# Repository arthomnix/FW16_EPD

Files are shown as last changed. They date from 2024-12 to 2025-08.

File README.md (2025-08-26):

# Framework Laptop 16 Touchscreen E-Paper Input Module

Touchscreen E-paper medium size input module for the Framework Laptop 16

_As featured on the [Framework 16 product page](https://frame.work/laptop16) and [Framework 2nd Gen Event](https://www.youtube.com/watch?v=-8k7jTF_JCg)_

Picture of prototype touchscreen e-paper input module installed in the right hand side of a Framework Laptop 16, showing the Framework logo and handwritten text saying 'Hi!'

**Firmware and software:** https://github.com/arthomnix/epd_firmware (also mirrored on [Tangled](https://tangled.sh/@arthomnix.dev/eepy))

## Legal

Copyright © 2024 arthomnix

This work is licensed under [Creative Commons Attribution-ShareAlike 4.0 International](https://creativecommons.org/licenses/by-sa/4.0).

Framework Laptop 16 Input Module footprints (`InputModule.pretty` folder) © 2023 Framework Computer, Inc. Licensed under [Creative Commons Attribution 4.0 International](https://creativecommons.org/licenses/by/4.0). Original available at https://github.com/FrameworkComputer/InputModules.

Hirose FH34SRJ footprints and symbols (`Hirose_FPC.pretty` folder; `FH34SRJ_*.kicad_sym`) © 2013-2024 SnapMagic. Licensed under [Creative Commons Attribution-ShareAlike 4.0 International](https://creativecommons.org/licenses/by-sa/4.0) with [Design Exception 1.0](https://www.snapeda.com/about/FAQ/#designexception). Originals available at https://www.snapeda.com/parts/FH34SRJ-6S-0.5SH%2850%29/Hirose%20Electric/view-part and https://www.snapeda.com/parts/FH34SRJ-24S-0.5SH%2850%29/Hirose%20Electric/view-part.

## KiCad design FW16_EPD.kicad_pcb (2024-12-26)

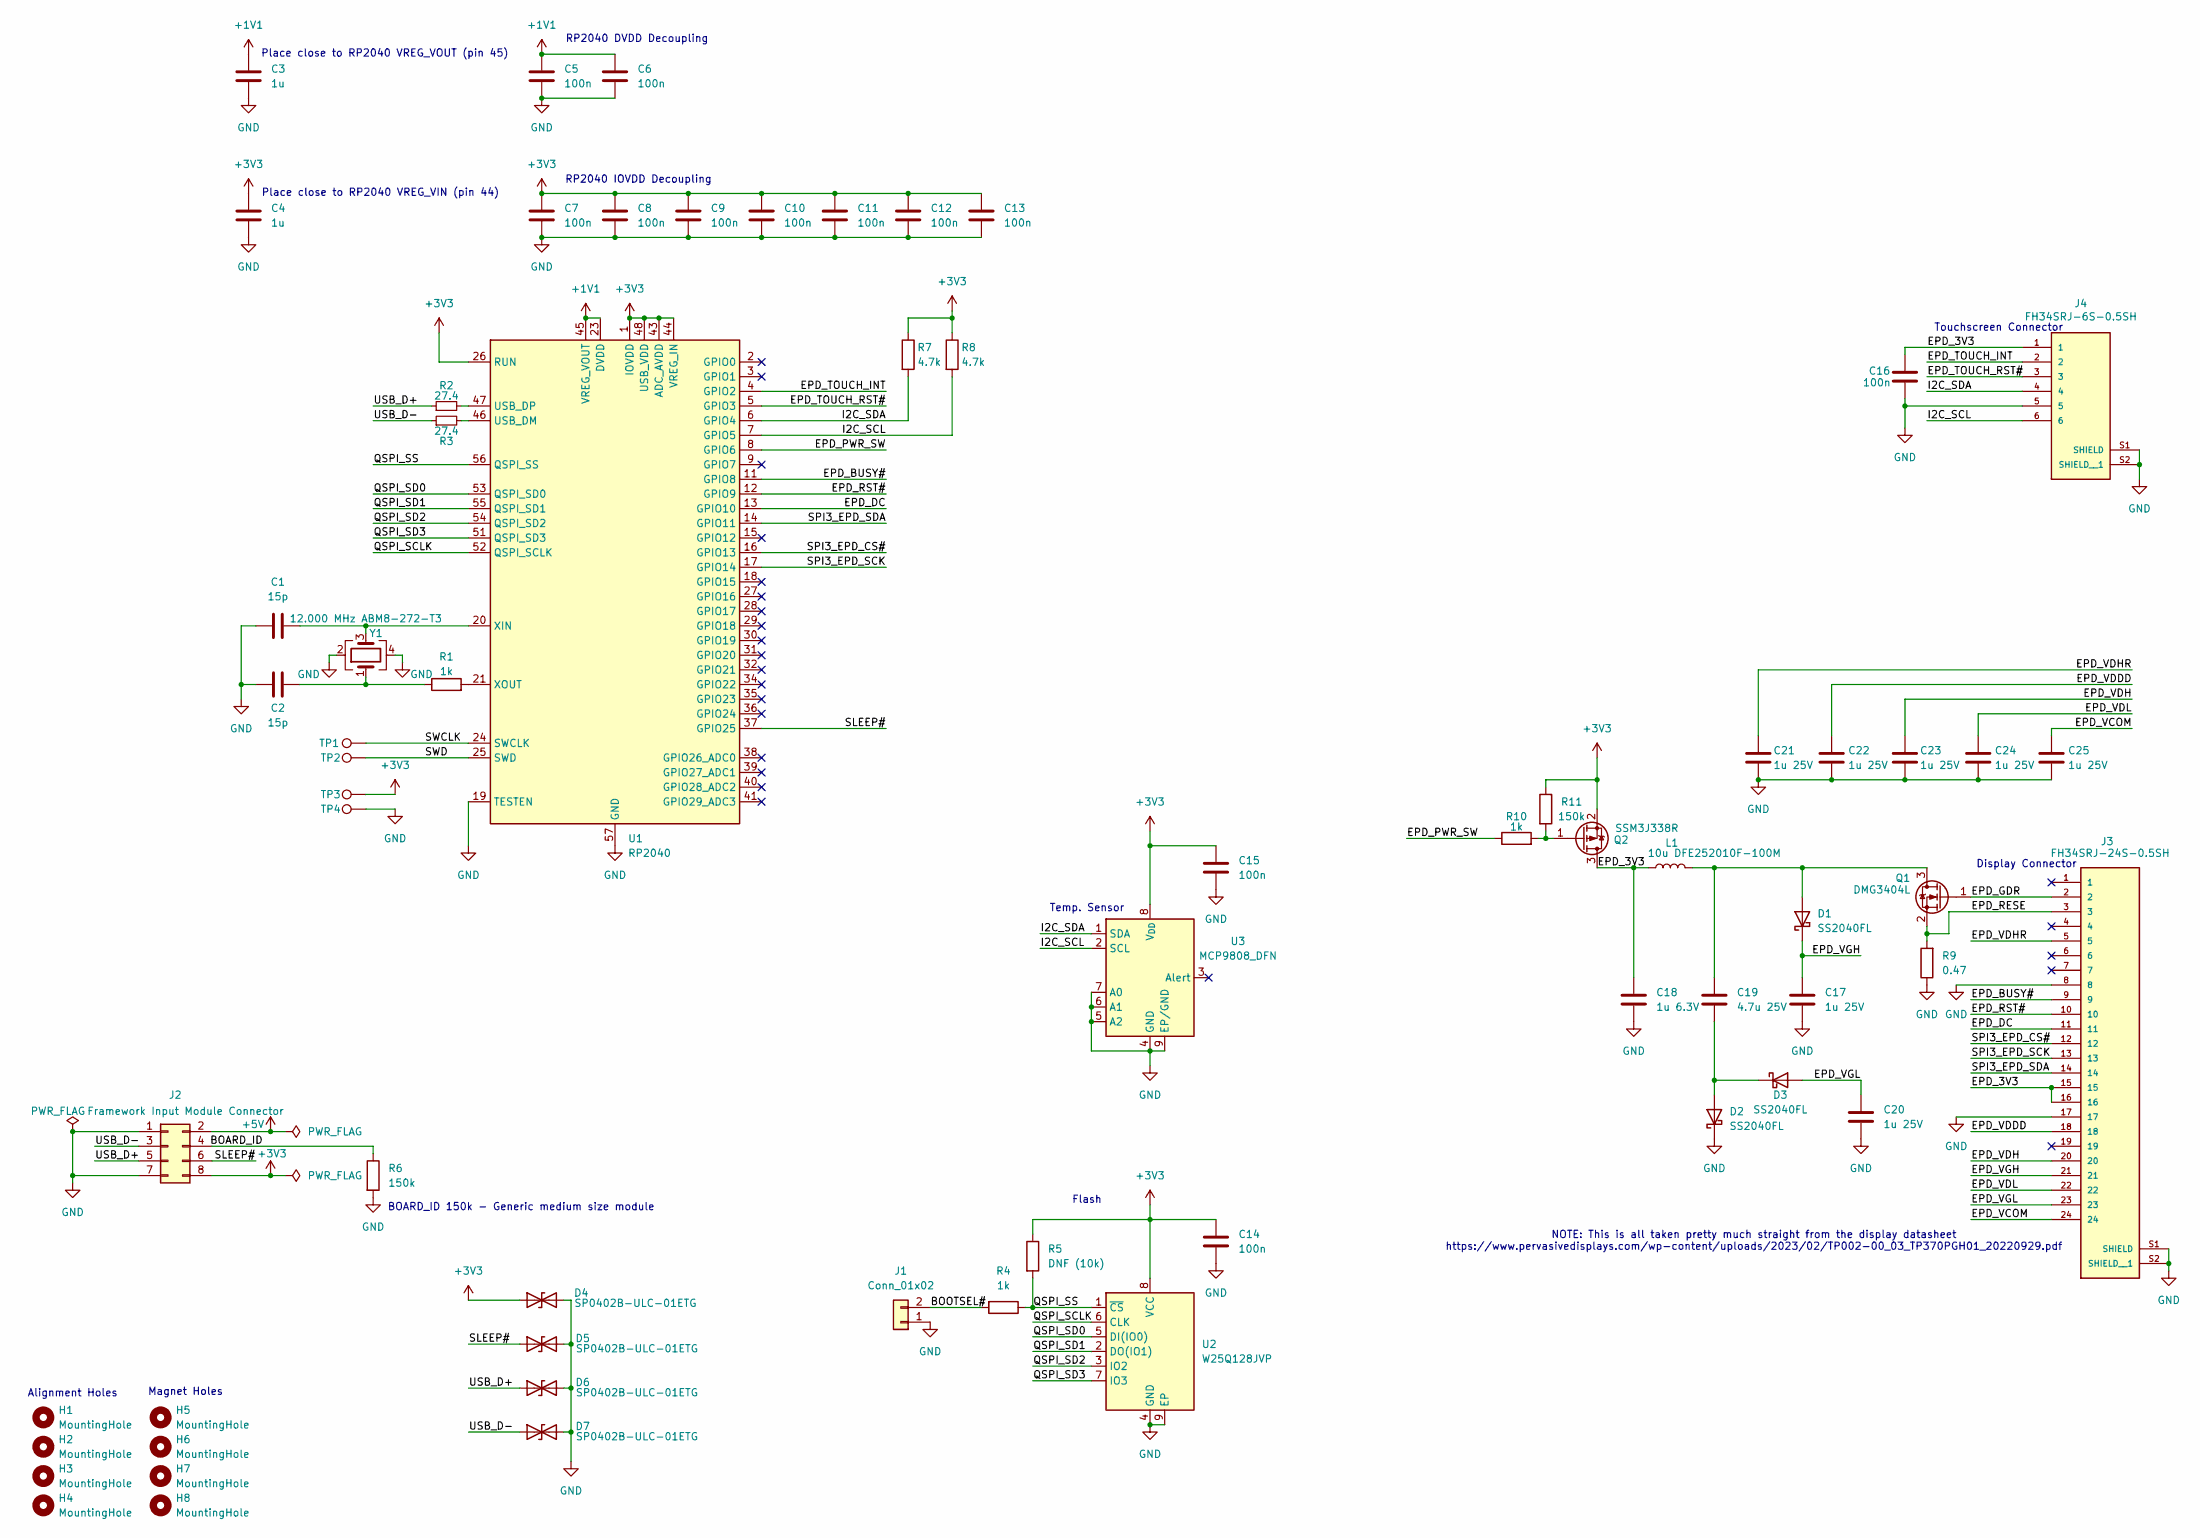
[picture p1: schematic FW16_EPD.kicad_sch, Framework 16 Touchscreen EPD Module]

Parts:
C1, C2: 15p; C_0402_1005Metric
C3, C4: 1u; C_0402_1005Metric
C5, C6, C7, C8, C9, C10, C11, C12, C13, C14, C15, C16: 100n; C_0402_1005Metric
C17, C20, C21, C22, C23, C24, C25: 1u 25V; C_0402_1005Metric
C18: 1u 6.3V; C_0402_1005Metric
C19: 4.7u 25V; C_0603_1608Metric
D1, D2, D3: SS2040FL; D_SOD-123F
D4, D5, D6, D7: SP0402B-ULC-01ETG; D_0402_1005Metric
H1, H2, H3, H4: MountingHole; MountingHole_2.1mm
H5, H6, H7, H8: MountingHole; MountingHole_3.7mm_Pad_24929
J1: Conn_01x02; SolderJumper-2_P1.3mm_Open_Pad1.0x1.5mm
J2: Framework Input Module Connector; PogoPads_2x4_P2.0mm
J3: FH34SRJ-24S-0.5SH; HRS_FH34SRJ-24S-0.5SH_50_
J4: FH34SRJ-6S-0.5SH; HRS_FH34SRJ-6S-0.5SH_50_
L1: 10u DFE252010F-100M; L_1008_2520Metric
Q1: DMG3404L; SOT-23
Q2: SSM3J338R; SOT-23
R1, R4, R10: 1k; R_0402_1005Metric
R2, R3: 27.4; R_0402_1005Metric
R5: DNF (10k); R_0402_1005Metric
R6, R11: 150k; R_0402_1005Metric
R7, R8: 4.7k; R_0402_1005Metric
R9: 0.47; R_0402_1005Metric
TP1, TP2, TP3, TP4: TestPoint; TestPoint_Pad_D2.5mm
U1: RP2040; QFN-56-1EP_7x7mm_P0.4mm_EP3.2x3.2mm
U2: W25Q128JVP; WSON-8-1EP_6x5mm_P1.27mm_EP3.4x4.3mm
U3: MCP9808_DFN; DFN-8-1EP_3x2mm_P0.5mm_EP1.7x1.4mm
Y1: 12.000 MHz ABM8-272-T3; Crystal_SMD_Abracon_ABM8G-4Pin_3.2x2.5mm

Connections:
+1V1: C3.1, C5.1, C6.1, U1.23 (DVDD), U1.45 (VREG_VOUT), U1.50 (DVDD)
+3V3: C4.1, C7.1, C8.1, C9.1, C10.1, C11.1, C12.1, C13.1, C14.1, C15.1, D4.1 (A1), J2.8, Q2.2 (S), R5.1, R7.1, R8.1, R11.1, TP3.1, U1.1 (IOVDD), U1.10 (IOVDD), U1.22 (IOVDD), U1.26 (RUN), U1.33 (IOVDD), U1.42 (IOVDD), U1.43 (ADC_AVDD), U1.44 (VREG_IN), U1.48 (USB_VDD), U1.49 (IOVDD), U2.8 (VCC), U3.8 (V_{DD})
+5V: J2.2
/BOARD_ID: J2.4, R6.1
/BOOTSEL#: J1.2, R4.2
/EPD_3V3: C16.2, C18.1, J3.15, J3.16, J4.1, L1.1, Q2.3 (D)
/EPD_BUSY#: J3.9, U1.11 (GPIO8)
/EPD_DC: J3.11, U1.13 (GPIO10)
/EPD_GDR: J3.2, Q1.1 (G)
/EPD_PWR_SW: R10.1, U1.8 (GPIO6)
/EPD_RESE: J3.3, Q1.2 (S), R9.2
/EPD_RST#: J3.10, U1.12 (GPIO9)
/EPD_TOUCH_INT: J4.2, U1.4 (GPIO2)
/EPD_TOUCH_RST#: J4.3, U1.5 (GPIO3)
/EPD_VCOM: C25.1, J3.24
/EPD_VDDD: C22.1, J3.18
/EPD_VDH: C23.1, J3.20
/EPD_VDHR: C21.1, J3.5
/EPD_VDL: C24.1, J3.22
/EPD_VGH: C17.1, D1.1 (K), J3.21
/EPD_VGL: C20.1, D3.2 (A), J3.23
/I2C_SCL: J4.6, R8.2, U1.7 (GPIO5), U3.2 (SCL)
/I2C_SDA: J4.4, R7.2, U1.6 (GPIO4), U3.1 (SDA)
/QSPI_SCLK: U1.52 (QSPI_SCLK), U2.6 (CLK)
/QSPI_SD0: U1.53 (QSPI_SD0), U2.5 (DI(IO0))
/QSPI_SD1: U1.55 (QSPI_SD1), U2.2 (DO(IO1))
/QSPI_SD2: U1.54 (QSPI_SD2), U2.3 (IO2)
/QSPI_SD3: U1.51 (QSPI_SD3), U2.7 (IO3)
/QSPI_SS: R4.1, R5.2, U1.56 (QSPI_SS), U2.1 (~CS)
/SLEEP#: D5.1 (A1), J2.6, U1.37 (GPIO25)
/SPI3_EPD_CS#: J3.12, U1.16 (GPIO13)
/SPI3_EPD_SCK: J3.13, U1.17 (GPIO14)
/SPI3_EPD_SDA: J3.14, U1.14 (GPIO11)
/SWCLK: TP1.1, U1.24 (SWCLK)
/SWD: TP2.1, U1.25 (SWD)
/USB_D+: D6.1 (A1), J2.5, R2.1
/USB_D-: D7.1 (A1), J2.3, R3.1
GND: C1.1, C2.1, C3.2, C4.2, C5.2, C6.2, C7.2, C8.2, C9.2, C10.2, C11.2, C12.2, C13.2, C14.2, C15.2, C16.1, C17.2, C18.2, C20.2, C21.2, C22.2, C23.2, C24.2, C25.2, D2.1 (K), D4.2 (A2), D5.2 (A2), D6.2 (A2), D7.2 (A2), J1.1, J2.1, J2.7, J3.8, J3.17, J3.S1 (SHIELD), J3.S2 (SHIELD__1), J4.5, J4.S1 (SHIELD), J4.S2 (SHIELD__1), R6.2, R9.1, TP4.1, U1.19 (TESTEN), U1.57 (GND), U2.4 (GND), U2.9 (EP), U3.4 (GND), U3.5 (A2), U3.6 (A1), U3.7 (A0), U3.9 (EP/GND), Y1.2, Y1.4
unnamed: C2.2, R1.1, Y1.1
unnamed: C19.1, D1.2 (A), L1.2, Q1.3 (D)
unnamed: C19.2, D2.2 (A), D3.1 (K)
unnamed: Q2.1 (G), R10.2, R11.2
unnamed: R3.2, U1.46 (USB_DM)
unnamed: R2.2, U1.47 (USB_DP)
unnamed: C1.2, U1.20 (XIN), Y1.3
unnamed: R1.2, U1.21 (XOUT)

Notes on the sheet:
NOTE: This is all taken pretty much straight from the display datasheet https://www.pervasivedisplays.com/wp-content/uploads/2023/02/TP002-00_03_TP370PGH01_20220929.pdf
Magnet Holes
Place close to RP2040 VREG_VOUT (pin 45)
RP2040 DVDD Decoupling
Flash
Touchscreen Connector
RP2040 IOVDD Decoupling
Display Connector
BOARD_ID 150k - Generic medium size module
Place close to RP2040 VREG_VIN (pin 44)
Alignment Holes
Temp. Sensor

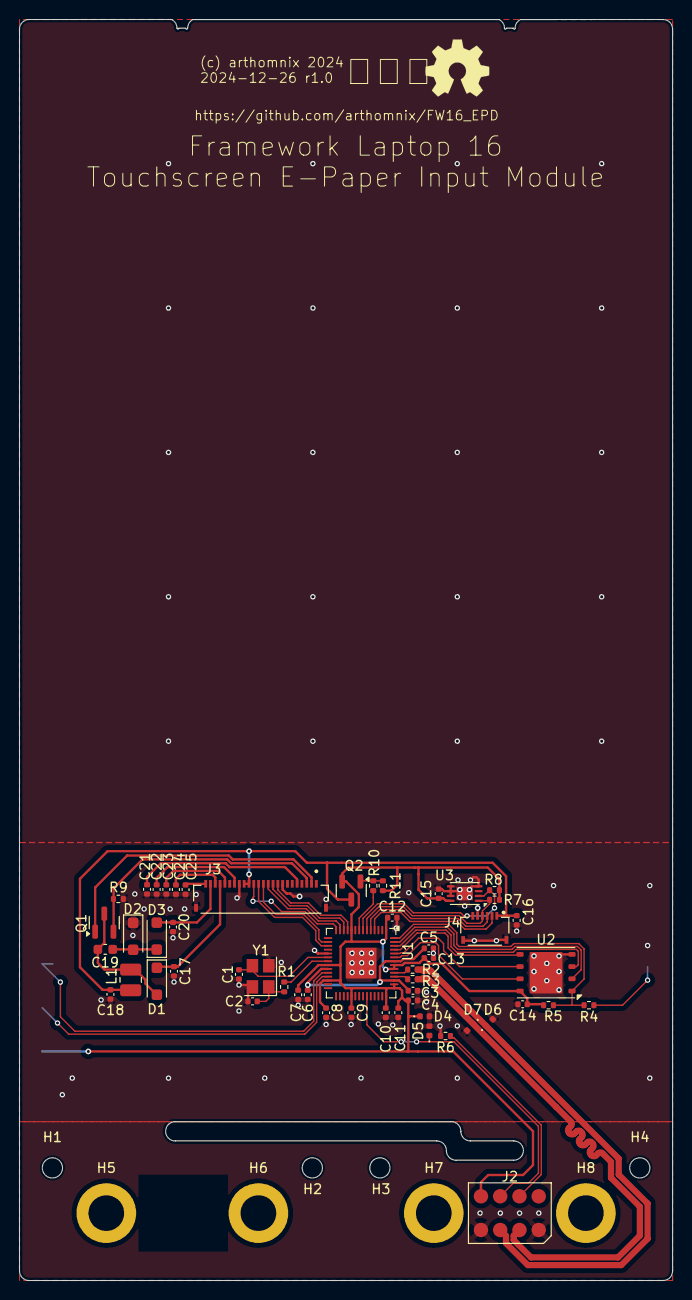
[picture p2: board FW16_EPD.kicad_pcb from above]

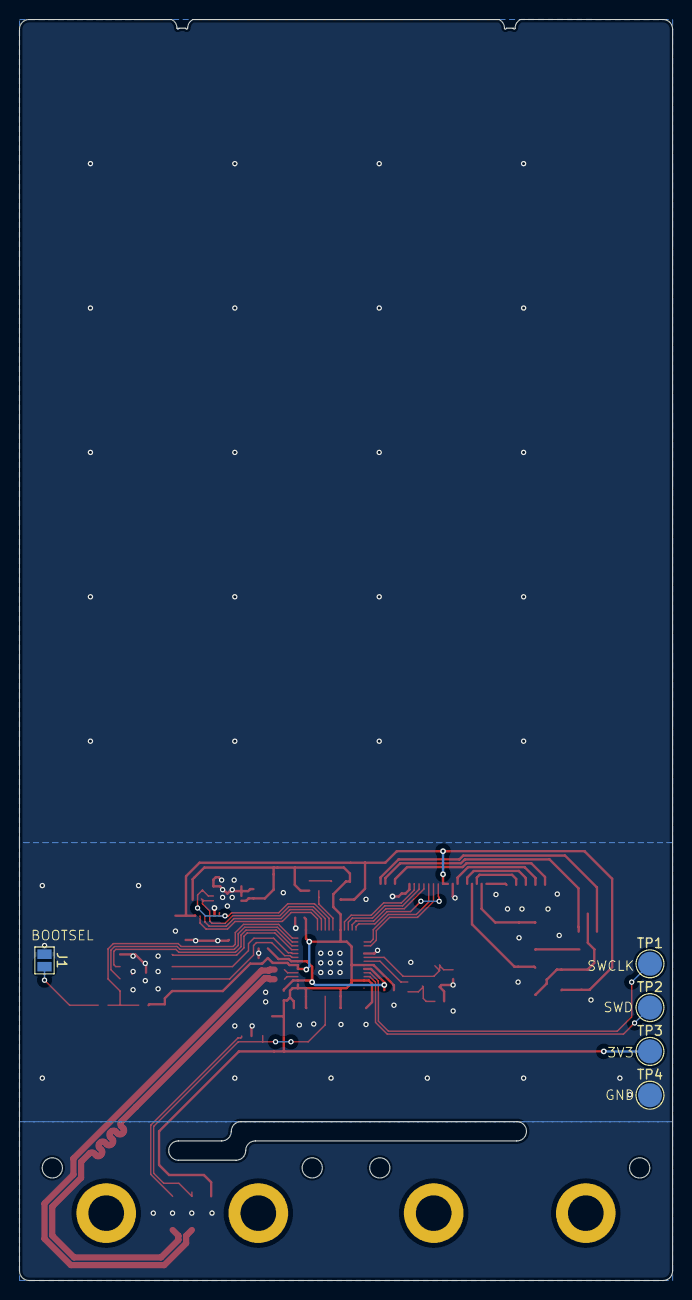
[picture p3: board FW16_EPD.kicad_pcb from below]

Board: 2 copper layers, 67.8 x 131.0 mm, 66 parts (5 on the bottom side), 45 nets.

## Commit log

2024-07-09 pcb: add CC and OSHW symbols; silkscreen rearrangements
    [FW16_EPD.kicad_pcb]
2024-07-10 sch/pcb: add TVS diodes; thicker traces for EPD DC/DC
    [FW16_EPD.kicad_pcb, FW16_EPD.kicad_sch]
2024-07-10 pcb: update dates
    [FW16_EPD.kicad_pcb]
2024-07-10 pcb: measurements corrections
    [FW16_EPD.kicad_pcb]
2024-07-11 pcb: clean up epd gnd connection
    [FW16_EPD.kicad_pcb]
2024-07-11 pcb: set solder mask expansion for JLC
    [FW16_EPD.kicad_pcb]
2024-07-11 pcb: more closely match reference board outline
    [FW16_EPD.kicad_pcb]
2024-10-03 finishing touches
    [FW16_EPD.kicad_pcb, FW16_EPD.kicad_sch]
2024-11-28 move spi3 traces away from crystal
    [FW16_EPD.kicad_pcb]
2024-11-29 update date
    [FW16_EPD.kicad_pcb]
2024-12-03 move crystal for better clearance with FFC
    [FW16_EPD.kicad_pcb]
2024-12-05 add 3d models for fpc
    [FW16_EPD.kicad_pcb]
2024-12-26 remove paste layer from hole footprint
    [FW16_EPD.kicad_pcb]
